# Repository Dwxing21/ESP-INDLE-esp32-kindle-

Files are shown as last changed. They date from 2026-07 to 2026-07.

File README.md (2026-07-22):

# ESPINDLE — DIY e-reader (ESP32-S3 + ILI9341 TFT)

A small, portable e-reader for manga, comics, and EPUB books. Built around
an **ESP32-S3 DevKit** and a **2.8" ILI9341 SPI TFT with an onboard
microSD slot**, in a 3D-printed case. Reads pages off the SD card, can
import `.epub` files directly on-device (no PC needed), and shows a
custom boot splash on power-up.

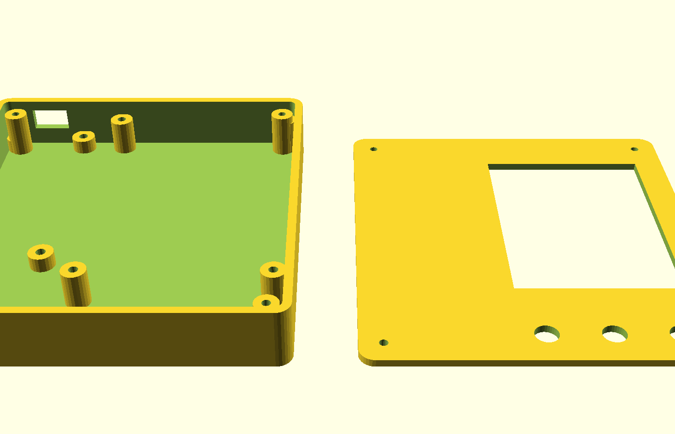
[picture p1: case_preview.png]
case preview


---

## Features
- **Manga / comic reader** — 240×320 JPEG pages off the SD card
- **EPUB import on-device** — drop `.epub` files onto the SD card, the
  device unpacks, re-flows, and paginates them into the library
- **Custom boot splash** — a 240×320 JPEG baked into flash, shown
  immediately on power-up before the SD card finishes initializing
- **Sleep / wake** — backlight dims to off after 5 minutes idle; any
  button press wakes it
- **3-button control** — Next, Previous, and a Select/Back button
  (short press = select, long press = back)

---

## Parts list
- **ESP32-S3 DevKit** — any generic ESP32-S3-DevKitC-1 (N16R8, N8R2, etc.
  all fine; ~€5-8)
- **2.8" ILI9341 SPI TFT with onboard microSD slot** — make sure the
  listing says **ILI9341** (not ST7789/ILI9488) and **SPI** (not
  parallel). Touch or non-touch doesn't matter. (~€4-7)
- **3× momentary tactile push buttons** — the small 4-leg square kind
  used on breadboards
- **microSD card** — 32 GB or less, formatted **FAT32**
- **Breadboard + jumper wires** — half-size or full-size breadboard,
  male-male and male-female jumpers
- Optional: **LiPo battery + TP4056** charge/protection board for
  portable use

**Total: ~€20-30** depending on supplier.

---

## 1. Wiring

Your 2.8" ILI9341 board shares one SPI bus between the screen and the
SD card — you only wire SCK/MOSI/MISO once, then give the screen and
the SD card their own chip-select (CS) lines.

| Screen/SD pin | ESP32-S3 GPIO | Notes |
|---|---|---|
| VCC | 3.3V | **Not 5V** — most of these boards are 3.3V only |
| GND | GND | |
| CS (TFT_CS) | GPIO 10 | Screen chip-select |
| RESET | GPIO 8 | |
| DC / RS | GPIO 9 | |
| SDI / MOSI | GPIO 11 | Shared with SD |
| SCK | GPIO 12 | Shared with SD |
| SDO / MISO | GPIO 13 | Shared with SD |
| LED (backlight) | GPIO 14 | PWM-driven for dimming/sleep |
| SD_CS | GPIO 15 | SD card chip-select |
| SD_MOSI/SCK/MISO | (same as above) | Same physical wires as the screen |

| Button | ESP32-S3 GPIO | Wiring |
|---|---|---|
| Next page | GPIO 4 | Button between pin and GND (internal pull-up used) |
| Previous page | GPIO 5 | Same |
| Select / Back | GPIO 6 | Short press = select, long press = back |

> **4-leg tactile buttons — check the orientation.** Most small tactile
> buttons have 4 legs arranged in 2 pairs: two legs on one side are
> permanently connected to each other, and the two legs on the other
> side are permanently connected to each other. Pressing the button
> bridges *those two pairs* together — it does **not** connect all 4
> legs. If you accidentally wire both your GPIO and GND wires to legs
> on the *same* side, the pin will read as permanently pressed (always
> LOW) whether you press it or not, and the button will appear
> completely dead. Use a multimeter's continuity mode to confirm: two
> legs should read "connected" with the button untouched, and only
> pressing it should connect the other two.

> These GPIOs are just a sensible default free of conflicts with
> USB/flash pins on most S3 boards. If your specific board already uses
> GPIO 8/9/10 for something else (check its pinout diagram), just change
> the `#define` values at the top of `espindle.ino` to match — nothing
> else needs to change.

Power the whole thing from the ESP32-S3's 5V/USB input; the board's
onboard regulator supplies 3.3V to itself, and you tap 3.3V from the
ESP32-S3 for the screen/SD.

---

## 2. Arduino IDE setup

1. Install **Arduino IDE 2.x**.
2. Add the ESP32 board package: *File → Preferences → Additional Board
   URLs* →
   `https://raw.githubusercontent.com/espressif/arduino-esp32/gh-pages/package_esp32_index.json`
3. *Tools → Board → Boards Manager* → search "esp32" → install the
   Espressif package.
4. Select your board: *Tools → Board → ESP32 Arduino → ESP32S3 Dev
   Module*.
5. Install libraries via *Sketch → Include Library → Manage Libraries*:
   - **Adafruit GFX Library**
   - **Adafruit ILI9341**
   - **TJpg_Decoder** (by Bodmer)
   - **unzipLIB** (by bitbank2) — needed for the on-device EPUB
     import feature
   - `SD` is bundled with the ESP32 core — no install needed.
6. **Important:** open the sketch by opening the `espindle.ino` file
   directly. `splash_jpeg.h` must live in the **same folder** as
   `espindle.ino` — the firmware `#include`s it with a relative path,
   so if you move or rename the header the build will fail.
7. Select the correct COM port and upload.

---

## 3. The boot splash

The splash image is **baked into flash** as a PROGMEM byte array in
`splash_jpeg.h` — there's no splash file to copy to the SD card. It
shows up immediately on power-up and stays on screen through the SD
card initialization (the slowest step of boot), so the user always gets
visual feedback within a second of plugging in.

To change the splash to your own image:
1. Get a JPEG you like, ideally already 240×320 (or close to that
   aspect ratio).
2. Run `img.py` against it to resize and re-encode:
   ```bash
   python3 img.py
   ```
   (Edit the `img.py` source/filenames if needed — by default it reads
   `espindel boot screen.jpg` and writes `splash.jpg`.)
3. Replace the `splash_jpeg` byte array in `splash_jpeg.h` with the
   bytes of the new file. Easiest way:
   ```bash
   xxd -i splash.jpg | sed 's/splash_jpg/splash_jpeg/g' > splash_jpeg.h
   ```
   then update the `#define SPLASH_JPEG_LEN` line at the top to the
   new file's byte count.

If the splash JPEG is corrupted or missing, the firmware will simply
fall back to a black screen during boot — the rest of the app still
works.

---

## 4. Preparing the SD card

1. Format the microSD card as **FAT32**.
2. Create this folder structure on it:
   ```
   /manga/One Piece/Chapter 1001/001.jpg
   /manga/One Piece/Chapter 1001/002.jpg
   /manga/Berserk/Chapter 001/001.jpg
   ```
3. Filenames inside a chapter must be **zero-padded and sequential**
   (`001.jpg`, `002.jpg`, …) so they sort correctly — the firmware
   sorts pages alphabetically.
4. Insert the card into the reader's SD slot before powering on.

The section below shows how to generate exactly this structure
automatically.

---

## 5. Getting manga/comics onto the SD card as JPEGs

A quick note first: only load content you're legally entitled to read
this way — things like your own scanned physical volumes, comics you've
bought as digital files (CBZ/CBR/PDF), or officially released
free/public-domain comics. Pirating scans isn't something I'll help
source.

### Where your source files usually come from
- **Digital purchases** (ComiXology/Kindle, Book Walker, publisher
  storefronts) — usually download as CBZ, CBR, EPUB, or PDF.
- **Your own scans** of physical volumes — typically end up as a
  folder of JPG/PNG or a PDF from your scanning software.
- **Public domain / Creative-Commons comics** — usually distributed
  directly as image sets or PDFs.

### Step A — Get everything into loose image files
- **CBZ** files are literally ZIP archives — rename `.cbz` to `.zip`
  (or just open with any archive tool) and extract.
- **CBR** files are RAR archives — extract with 7-Zip, WinRAR, or
  `unar`, then treat like CBZ.
- **PDF** source — extract each page as an image:
  - **Free tool (all platforms):** [XnConvert](https://www.xnview.com/en/xnconvert/)
    or `pdftoppm` (part of Poppler) — e.g. `pdftoppm -jpeg book.pdf page`
  - **Mac:** Preview → File → Export as JPEG, or use `sips`/`pdftoppm`
    via Homebrew.
  - **Windows:** Poppler for Windows (`pdftoppm.exe`) or any free
    "PDF to JPG" desktop tool.

### Step B — Resize, rename, and organize automatically
Doing this by hand for hundreds of pages is painful, so use the
included **`prepare_manga.py`** script. It takes a folder of images
(or CBZ files) and outputs a properly-sized, correctly-named
`/manga/...` folder tree ready to drop onto the SD card.

```bash
pip install pillow

# From a folder of loose images:
python prepare_manga.py --input "path/to/OnePiece_Ch1001" --series "One Piece" --chapter "Chapter 1001" --output "SD_CARD_ROOT/manga"

# Directly from a CBZ file:
python prepare_manga.py --input "path/to/Berserk_001.cbz" --series "Berserk" --chapter "Chapter 001" --output "SD_CARD_ROOT/manga"
```

Point `--output` at the `manga` folder on your actual SD card (once
it's mounted on your computer) and the script writes the finished
folder structure directly onto it. Run it once per chapter, or see the
`--batch` option in the script for converting a whole folder of
chapter subfolders at once.

The script:
- Resizes/crops each page to fit the 240×320 screen (preserving
  aspect ratio, so no stretching)
- Converts everything to JPEG at a size-friendly quality (85) so
  pages load fast off the SD card
- Renames pages sequentially as `001.jpg`, `002.jpg`, … so they
  always sort correctly
- Unpacks CBZ files automatically if you point `--input` at a `.cbz`
  instead of a folder

### Step C — Load the card
Copy (or let the script write directly to) the finished
`manga/<Series>/<Chapter>/*.jpg` folders onto the SD card, eject
safely, and insert into the reader.

---

## 6. EPUB import (on-device)

See **[EPUB_IMPORT.md](EPUB_IMPORT.md)** for the full guide. Short
version: drop `.epub` files into `/epub_import/` on the SD card, pick
**+ Import EPUB...** from the main menu on the device, and the
ESP32-S3 itself unpacks, re-flows, and paginates them into the
library.

---

## 7. Using the reader
- **Next / Previous** buttons move through the series list, chapter
  list, or pages depending on where you are.
- **Select** (short press) confirms a menu choice, or shows a
  page-number overlay while reading.
- **Select** (long press, ~0.6s) goes back a menu level.
- After 5 minutes idle, the backlight turns off to save power; any
  button press wakes it (the first press just wakes the screen and is
  otherwise ignored).

---

## Files in this repo
- `espindle.ino` — the main firmware
- `splash_jpeg.h` — the boot splash image, baked into flash
- `prepare_manga.py` — PC-side script for resizing/renaming comic
  pages onto the SD card
- `case.scad` / `case_base.stl` / `case_lid.stl` / `case_preview.png`
  — the 3D-printed case
- `EPUB_IMPORT.md` — detailed EPUB import guide
- `img.py` — utility for regenerating `splash_jpeg.h` from a new
  source image

---

## License / content notice
This project is just hardware and code. **What you read on it is your
responsibility** — only load books and comics you're legally entitled
to read this way (your own purchases, public domain works, your own
scans of physical media you own, etc.).

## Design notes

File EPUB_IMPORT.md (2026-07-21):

# EPUB Import — On-Device, No PC Needed

## What it does
Adds a **"+ Import EPUB..."** entry at the top of the main menu. Selecting
it lets you pick any `.epub` file sitting in a folder on the SD card, and
the ESP32-S3 itself unzips it, extracts the chapter text, re-flows it to
fit the screen, and saves it into your library — all on the device, no
computer involved.

## How to use it
1. Copy `.epub` files onto the SD card into a folder named `/epub_import`
   (the firmware creates this folder automatically on first boot if it
   doesn't exist yet — you just need to drop files into it).
2. On the device, open the main menu and select **+ Import EPUB...**
3. Pick a file from the list and press Select.
4. Wait while it converts — you'll see a progress screen counting through
   chapters (this can take anywhere from several seconds to a couple of
   minutes depending on the book's length; text-only books are much
   faster than image-heavy ones since there's no JPEG decoding involved).
5. When it's done, you're dropped back at the main menu with the new book
   already in your library, ready to read with the exact same
   Next/Prev/Select controls as manga chapters.

## What it can and can't do
- **Can:** extract and paginate the actual reading text of standard
  "reflowable" EPUB books — novels, most non-fiction, etc.
- **Can't:** render embedded images, custom fonts, complex CSS layouts,
  or "fixed layout" EPUBs (the kind used for comics/picture books — use
  the manga pipeline for those instead, via `prepare_manga.py`).
- The EPUB/HTML parsing uses lightweight pattern-matching rather than a
  full XML parser, to keep it practical on a microcontroller. It handles
  the great majority of real-world EPUB files correctly, but an unusual
  or malformed one could occasionally produce a slightly rough result
  (e.g. a stray heading picked up as a chapter title, or a missing
  chapter if its manifest entry is unusual). If a specific book converts
  oddly, let me know the details and I can tune the parser.

## Where things end up on the SD card
```
/epub_import/mybook.epub          <- source file you dropped in
/manga/My Book Title/
  001 - Chapter One/
    001.txt
    002.txt
    ...
  002 - Chapter Two/
    001.txt
    ...
```
This is the same folder structure as manga chapters, just with `.txt`
page files instead of `.jpg` — the reader already treats both the same
way once you're browsing the menu.

## Only import books you're legally entitled to read this way
Your own purchases, your own writing, and public domain works are all
fine. This feature converts files already on your SD card — it doesn't
fetch or download anything from anywhere.

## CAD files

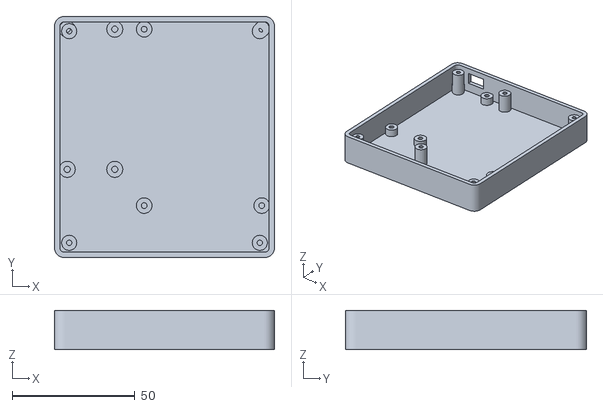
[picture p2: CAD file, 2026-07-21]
case_base.stl
89.8 x 98.4 x 16.0

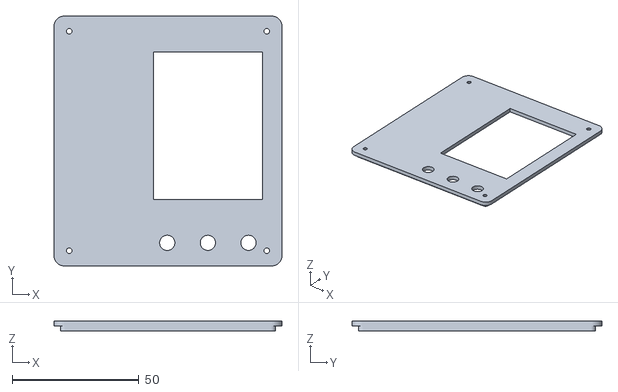
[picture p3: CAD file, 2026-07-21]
case_lid.stl
89.8 x 98.4 x 4.00

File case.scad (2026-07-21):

// ============================================================
// ESPINDLE Case — parametric OpenSCAD source
// ============================================================
// MEASURE YOUR OWN BOARDS WITH CALIPERS AND ADJUST THE VALUES
// BELOW BEFORE PRINTING. The defaults are typical sizes for a
// generic 2.8" ILI9341 SPI+SD breakout and an ESP32-S3-DevKitC-1
// style board, but real dimensions vary between suppliers.
// ============================================================

// ---------- Which part to render ----------
// "base" = bottom shell (holds the boards)
// "lid"  = top shell (screen window + buttons)
// "both" = both, side by side (preview only, don't print this way)
PART = "both"; // [base, lid, both]

// ---------- General ----------
wall        = 2.2;   // outer wall thickness
floor_t     = 2.0;   // base floor thickness
lid_t       = 2.0;   // lid thickness
gap         = 0.3;   // clearance between base walls and lid
corner_r    = 4;     // outer corner rounding radius

// ---------- TFT board (2.8" ILI9341 + SD) ----------
tft_w       = 54;    // board width (short axis)
tft_h       = 78;    // board length (long axis, includes header strip)
tft_thick   = 3.2;   // board PCB + connector thickness, for standoff height
tft_active_w = 43;   // visible screen width
tft_active_h = 58;   // visible screen height
tft_active_off_x = (tft_w - tft_active_w) / 2; // horizontal centering — adjust if off-center on your board
tft_active_off_y = 8;                          // gap from top edge of board to top of visible screen — MEASURE THIS
tft_mount_inset  = 3; // distance from board edge to its mounting-hole centers (adjust to your board's holes)
tft_hole_dia     = 2.4; // screw/standoff hole diameter for TFT board

// ---------- ESP32-S3 DevKitC-1 style board ----------
esp_w       = 25.4;
esp_h       = 63.2;
esp_thick   = 8;     // clearance height needed under/around the board (USB connector, headers)
esp_mount_inset = 3;
esp_hole_dia    = 2.6;

// ---------- Buttons (3x, front edge of lid, thumb reach) ----------
btn_hole_dia = 6.0;
btn_spacing  = 16;

// ---------- Print bed ----------
// da Vinci mini's actual spec'd build volume is 150x150x150mm — designing
// to this (with a small margin) fits both that and a 160x160 bed.
max_plate_xy = 148;

// ---------- Layout (side-by-side, not stacked — keeps the case short) ----------
column_gap    = 6;    // horizontal gap between the TFT and ESP32 columns, for wiring
button_zone_h = 16;   // strip reserved below the TFT board for buttons
lip_frame_w   = 2.5;  // width of the lid's thin alignment rim — must NOT cover the interior

inner_w = tft_w + column_gap + esp_w;
inner_h = tft_h + button_zone_h;                      // tallest column (TFT) + its button strip
inner_d = max(tft_thick, esp_thick) + 6;               // boards are side-by-side, so depth = the taller one, not the sum

outer_w = inner_w + 2 * wall;
outer_h = inner_h + 2 * wall;
outer_d = inner_d + floor_t + lid_t;

// Standoff post height for TFT board (raises its top surface near the lid window)
tft_standoff_h = inner_d - tft_thick - 1;
// Standoff post height for ESP32 board (mounted lower, doesn't need to reach the lid)
esp_standoff_h = 4;

echo(str("Overall case size (mm): ", outer_w, " x ", outer_h, " x ", outer_d));
if (outer_w > max_plate_xy || outer_h > max_plate_xy) {
  echo(str("*** WARNING: case footprint exceeds ", max_plate_xy, "mm — will NOT fit the print bed! ***"));
}

// ============================================================
// Helper modules
// ============================================================
module rounded_rect(w, h, r) {
  hull() {
    for (x = [r, w - r])
      for (y = [r, h - r])
        translate([x, y, 0]) circle(r = r, $fn = 32);
  }
}

module standoff(hole_dia, height) {
  difference() {
    cylinder(d = hole_dia + 4, h = height, $fn = 24);
    translate([0, 0, -0.5]) cylinder(d = hole_dia, h = height + 1, $fn = 16);
  }
}

// corner screw bosses joining base + lid (self-tapping screws, e.g. M2.5)
module corner_bosses(w, h, height, hole_dia = 2.2, inset = 6) {
  positions = [[inset, inset], [w - inset, inset], [inset, h - inset], [w - inset, h - inset]];
  for (p = positions)
    translate([p[0], p[1], 0])
      standoff(hole_dia, height);
}

// ============================================================
// BASE (bottom shell)
// ============================================================
module case_base() {
  // Both boards top-aligned to the same interior top edge; TFT column has a
  // button strip below it, ESP32 column has empty space below (for wiring/battery).
  esp_x = wall;
  tft_x = wall + esp_w + column_gap;
  tft_y = wall + button_zone_h; // top-aligned with esp_y + esp_h below
  esp_y = wall + inner_h - esp_h; // top-aligned to same interior top as TFT

  difference() {
    union() {
      // outer shell
      linear_extrude(height = floor_t + inner_d)
        rounded_rect(outer_w, outer_h, corner_r);
    }
    // hollow out interior, leave floor
    translate([wall, wall, floor_t])
      linear_extrude(height = inner_d + 1)
        rounded_rect(inner_w, inner_h, corner_r - wall > 0 ? corner_r - wall : 1);

    // USB-C access cutout — top wall, aligned to the ESP32 board's top edge
    // (adjust which wall this is on if your board's USB connector is elsewhere)
    translate([esp_x + esp_w/2 - 5, outer_h - wall - 1, floor_t + esp_standoff_h + 1])
      cube([10, wall + 2, 6]);
  }

  // TFT board standoffs
  translate([tft_x + tft_mount_inset, tft_y + tft_mount_inset, floor_t])
    standoff(tft_hole_dia, tft_standoff_h);
  translate([tft_x + tft_w - tft_mount_inset, tft_y + tft_mount_inset, floor_t])
    standoff(tft_hole_dia, tft_standoff_h);
  translate([tft_x + tft_mount_inset, tft_y + tft_h - tft_mount_inset, floor_t])
    standoff(tft_hole_dia, tft_standoff_h);
  translate([tft_x + tft_w - tft_mount_inset, tft_y + tft_h - tft_mount_inset, floor_t])
    standoff(tft_hole_dia, tft_standoff_h);

  // ESP32-S3 board standoffs
  translate([esp_x + esp_mount_inset, esp_y + esp_mount_inset, floor_t])
    standoff(esp_hole_dia, esp_standoff_h);
  translate([esp_x + esp_w - esp_mount_inset, esp_y + esp_mount_inset, floor_t])
    standoff(esp_hole_dia, esp_standoff_h);
  translate([esp_x + esp_mount_inset, esp_y + esp_h - esp_mount_inset, floor_t])
    standoff(esp_hole_dia, esp_standoff_h);
  translate([esp_x + esp_w - esp_mount_inset, esp_y + esp_h - esp_mount_inset, floor_t])
    standoff(esp_hole_dia, esp_standoff_h);

  // corner screw bosses (joins to lid)
  corner_bosses(outer_w, outer_h, floor_t + inner_d - 2);
}

// ============================================================
// LID (top shell)
// ============================================================
module case_lid() {
  esp_x = wall;
  tft_x = wall + esp_w + column_gap;
  tft_y = wall + button_zone_h;
  esp_y = wall + inner_h - esp_h;

  difference() {
    union() {
      linear_extrude(height = lid_t)
        rounded_rect(outer_w, outer_h, corner_r);
      // thin alignment rim (frame, not a plate) that nests inside the base walls —
      // only the outer lip_frame_w band is solid, the interior stays open so it
      // can never block the screen window, button holes, or wire routing space.
      translate([wall + gap, wall + gap, -2])
        linear_extrude(height = 2)
          difference() {
            rounded_rect(inner_w - 2*gap, inner_h - 2*gap, max(corner_r - wall, 1));
            translate([lip_frame_w, lip_frame_w, 0])
              rounded_rect(inner_w - 2*gap - 2*lip_frame_w, inner_h - 2*gap - 2*lip_frame_w,
                            max(corner_r - wall - lip_frame_w, 0.5));
          }
    }

    // screen window, aligned over the TFT board's active area
    // (cut depth -3 to lid_t+2 so it fully clears the rim's z=-2 to 0 span too)
    translate([tft_x + tft_active_off_x, tft_y + tft_active_off_y, -3])
      linear_extrude(height = lid_t + 5)
        square([tft_active_w, tft_active_h]);

    // button holes — centered under the TFT column's screen, in its button strip
    btn_y = button_zone_h / 2 + wall/2;
    btn_center_x = tft_x + tft_w/2;
    for (i = [-1, 0, 1])
      translate([btn_center_x + i * btn_spacing, btn_y, -3])
        cylinder(d = btn_hole_dia, h = lid_t + 5, $fn = 32);

    // corner screw holes (through-holes matching base bosses)
    positions = [[6, 6], [outer_w - 6, 6], [6, outer_h - 6], [outer_w - 6, outer_h - 6]];
    for (p = positions)
      translate([p[0], p[1], -3])
        cylinder(d = 2.2, h = lid_t + 5, $fn = 16);
  }
}
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

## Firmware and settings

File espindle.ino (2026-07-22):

/*
  ============================================================
  ESPINDLE — ESP32-S3 Manga/Comic/EPUB Reader
  (ESP + Kindle)
  ============================================================
  Hardware: ESP32-S3 DevKit + 2.8" ILI9341 SPI TFT w/ SD slot

  SD card layout expected:
    /manga/<Title>/<Chapter Name>/001.jpg   (image pages -- comics/manga)
    /manga/<Title>/<Chapter Name>/001.txt   (text pages -- imported EPUBs)
    ...
  (Use prepare_manga.py on a PC to generate the image version, or use
  the on-device "+ Import EPUB..." menu option to generate the text
  version directly from a .epub file dropped in /epub_import -- no PC
  needed for that path.)

  EPUB IMPORT NOTES:
  - Only import EPUB files you're legally entitled to read this way
    (your own books, purchases, public domain works) -- same principle
    as the manga content.
  - The importer only handles reflowable text content: chapter text is
    extracted and re-flowed to fit the screen. Embedded images, custom
    fonts, and complex CSS layouts in the EPUB are not rendered.
  - OPF/HTML parsing here uses lightweight heuristics (string search),
    not a full XML parser, to keep this practical on a microcontroller.
    It works on the great majority of real-world EPUB files but isn't
    guaranteed to handle every possible malformed or unusual one.

  Libraries required (install via Library Manager):
    - Adafruit GFX Library
    - Adafruit ILI9341
    - TJpg_Decoder (by Bodmer)
    - unzipLIB (by bitbank2)      <-- new, needed for EPUB import
    - SD (bundled with ESP32 core)

  Wiring: see WIRING_GUIDE.md
  ============================================================
*/

#include <SPI.h>
#include <SD.h>
#include <Adafruit_GFX.h>
#include <Adafruit_ILI9341.h>
#include <TJpg_Decoder.h>
#include <unzipLIB.h>
#include <vector>
#include <algorithm>
#include "splash_jpeg.h"

// ---------------- PIN CONFIG ----------------
// Shared SPI bus (TFT + SD)
#define PIN_SCK   12
#define PIN_MOSI  11
#define PIN_MISO  13

#define TFT_CS    10
#define TFT_DC    9
#define TFT_RST   8
#define TFT_LED   14   // backlight, PWM controlled

#define SD_CS     15

// Buttons (active LOW, wired to GND with internal pullups)
#define BTN_NEXT   4
#define BTN_PREV   5
#define BTN_SELECT 6

// ---------------- SCREEN ----------------
#define SCREEN_W 240
#define SCREEN_H 320

SPIClass spiBus = SPIClass(HSPI);
// Bound explicitly to spiBus (not the default global SPI object) so this
// works correctly regardless of what a given ESP32-S3 board's default
// hardware SPI pins happen to be.
Adafruit_ILI9341 tft = Adafruit_ILI9341(&spiBus, TFT_DC, TFT_CS, TFT_RST);

// ---------------- BACKLIGHT / SLEEP ----------------
#define IDLE_TIMEOUT_MS   (5UL * 60UL * 1000UL)  // 5 minutes
unsigned long lastActivity = 0;
bool screenDimmed = false;

// ---------------- LIBRARY / FOLDER LAYOUT ----------------
#define MANGA_ROOT       "/manga"
#define EPUB_IMPORT_DIR  "/epub_import"
static const char *IMPORT_EPUB_LABEL = "+ Import EPUB...";

// ---------------- TEXT PAGE LAYOUT (for imported EPUB chapters) ----------------
#define TEXT_SIZE        1   // Adafruit default font: 6px/char wide, 8px/line tall at size 1
#define TEXT_MARGIN      6
#define TEXT_CHAR_W      (6 * TEXT_SIZE)
#define TEXT_LINE_H      (8 * TEXT_SIZE)
#define TEXT_CHARS_PER_LINE  ((SCREEN_W - 2*TEXT_MARGIN) / TEXT_CHAR_W)
#define TEXT_LINES_PER_PAGE  ((SCREEN_H - 2*TEXT_MARGIN) / TEXT_LINE_H - 1) // -1 line of headroom

// ---------------- APP STATE ----------------
enum AppState { STATE_SERIES_MENU, STATE_CHAPTER_MENU, STATE_READING, STATE_EPUB_PICKER };
AppState appState = STATE_SERIES_MENU;

std::vector<String> seriesList;
std::vector<String> chapterList;
std::vector<String> pageList;
std::vector<String> epubFileList;

int seriesIndex = 0;
int chapterIndex = 0;
int pageIndex = 0;
int epubIndex = 0;
int menuScrollTop = 0;
const int MENU_VISIBLE_ROWS = 12;

String currentSeriesPath = "";
String currentChapterPath = "";

// ---------------- BUTTON DEBOUNCE ----------------
struct Button {
  uint8_t pin;
  bool rawState = HIGH;      // last raw (possibly bouncy) pin reading
  bool stableState = HIGH;   // debounce-confirmed state
  unsigned long lastChange = 0;
  unsigned long pressStart = 0;
  bool longPressFired = false;
};
Button btnNext   = {BTN_NEXT};
Button btnPrev   = {BTN_PREV};
Button btnSelect = {BTN_SELECT};

const unsigned long DEBOUNCE_MS   = 30;
const unsigned long LONGPRESS_MS  = 600;

// ---------------- EPUB IMPORT (unzipLIB) ----------------
UNZIP epubZip; // statically allocated per library docs (~41KB)
static File epubZipFile; // backing file for the SD callbacks below

// Callback functions unzipLIB needs to read a zip file from the SD card
// (pattern taken directly from the library's own SD card example --
// note the library passes a ZIPFILE* wrapper to close/read/seek, not the
// raw pointer returned by open(); the real File* lives in ->fHandle).
void *epubZipOpen(const char *filename, int32_t *size) {
  epubZipFile = SD.open(filename);
  if (!epubZipFile) { *size = 0; return NULL; }
  *size = epubZipFile.size();
  return (void *)&epubZipFile;
}
void epubZipClose(void *p) {
  ZIPFILE *pzf = (ZIPFILE *)p;
  File *f = (File *)pzf->fHandle;
  if (f) f->close();
}
int32_t epubZipRead(void *p, uint8_t *buffer, int32_t length) {
  ZIPFILE *pzf = (ZIPFILE *)p;
  File *f = (File *)pzf->fHandle;
  return f->read(buffer, length);
}
int32_t epubZipSeek(void *p, int32_t position, int iType) {
  ZIPFILE *pzf = (ZIPFILE *)p;
  File *f = (File *)pzf->fHandle;
  if (iType == SEEK_SET) return f->seek(position) ? position : -1;
  else if (iType == SEEK_END) return f->seek(pzf->iSize + position) ? (pzf->iSize + position) : -1;
  else { long l = f->position(); return f->seek(l + position) ? (l + position) : -1; }
}

// ============================================================
// JPEG DECODER CALLBACK — draws each decoded MCU block to TFT
// ============================================================
bool tft_output(int16_t x, int16_t y, uint16_t w, uint16_t h, uint16_t *bitmap) {
  if (y >= tft.height()) return 0;
  tft.drawRGBBitmap(x, y, bitmap, w, h);
  return 1;
}

// ============================================================
// SETUP
// ============================================================
void setup() {
  Serial.begin(115200);

  pinMode(BTN_NEXT, INPUT_PULLUP);
  pinMode(BTN_PREV, INPUT_PULLUP);
  pinMode(BTN_SELECT, INPUT_PULLUP);

  // Backlight PWM (ESP32 Arduino core 3.x pin-based LEDC API)
  ledcAttach(TFT_LED, 5000, 8); // pin, freq Hz, resolution bits
  ledcWrite(TFT_LED, 255);      // full brightness

  // Shared SPI bus for TFT + SD
  spiBus.begin(PIN_SCK, PIN_MISO, PIN_MOSI, TFT_CS);
  tft.begin();
  tft.setRotation(0); // portrait, best for manga pages
  tft.fillScreen(ILI9341_BLACK);

  // Boot splash: show the flash-baked splash.jpeg immediately so the user
  // sees feedback while SD init runs (the slowest part of boot).
  drawSplashFromFlash();

  if (!SD.begin(SD_CS, spiBus)) {
    drawFatalError("SD card not found!\nCheck wiring/card.");
    while (true) delay(1000);
  }

  if (!SD.exists(EPUB_IMPORT_DIR)) SD.mkdir(EPUB_IMPORT_DIR);

  TJpgDec.setJpgScale(1);
  TJpgDec.setSwapBytes(true);
  TJpgDec.setCallback(tft_output);

  loadSeriesList();
  drawMenu();

  lastActivity = millis();
}

// ============================================================
// MAIN LOOP
// ============================================================
void loop() {
  bool nextPressed   = readButton(btnNext);
  bool prevPressed   = readButton(btnPrev);
  bool selectPressed = readButtonWithLongPress(btnSelect);

  if (nextPressed || prevPressed || selectPressed) {
    lastActivity = millis();
    if (screenDimmed) {
      wakeScreen();
      return; // swallow the wake press
    }
  }

  handleIdleSleep();

  if (screenDimmed) { delay(20); return; }

  if (nextPressed)   handleNext();
  if (prevPressed)   handlePrev();
  if (selectPressed) handleSelect();

  delay(10);
}

// ============================================================
// BUTTON HELPERS
// ============================================================
bool readButton(Button &b) {
  bool reading = digitalRead(b.pin);
  bool pressed = false;

  if (reading != b.rawState) b.lastChange = millis();
  b.rawState = reading;

  if ((millis() - b.lastChange) > DEBOUNCE_MS) {
    if (reading != b.stableState) {
      b.stableState = reading;
      if (b.stableState == LOW) pressed = true; // confirmed press edge
    }
  }
  return pressed;
}

// SELECT button: short press = confirm, long press = back
// Returns true only on SHORT press release (confirm action)
bool readButtonWithLongPress(Button &b) {
  bool reading = digitalRead(b.pin);
  bool shortPress = false;

  if (reading != b.rawState) b.lastChange = millis();
  b.rawState = reading;

  if ((millis() - b.lastChange) > DEBOUNCE_MS) {
    if (reading != b.stableState) {
      // confirmed transition
      b.stableState = reading;
      if (b.stableState == LOW) {
        b.pressStart = millis();
        b.longPressFired = false;
      } else if (!b.longPressFired) {
        shortPress = true; // confirmed release, wasn't a long press
      }
    }

    // check for long-press while still held down
    if (b.stableState == LOW && !b.longPressFired) {
      if (millis() - b.pressStart > LONGPRESS_MS) {
        b.longPressFired = true;
        goBack();
      }
    }
  }
  return shortPress;
}

// ============================================================
// NAVIGATION LOGIC
// ============================================================
void handleNext() {
  if (appState == STATE_READING) {
    if (pageIndex < (int)pageList.size() - 1) {
      pageIndex++;
      showPage();
    }
  } else if (appState == STATE_EPUB_PICKER) {
    if (epubIndex < (int)epubFileList.size() - 1) { epubIndex++; drawEpubPickerMenu(); }
  } else {
    int count = (appState == STATE_SERIES_MENU) ? seriesList.size() : chapterList.size();
    int &idx = (appState == STATE_SERIES_MENU) ? seriesIndex : chapterIndex;
    if (idx < count - 1) { idx++; drawMenu(); }
  }
}

void handlePrev() {
  if (appState == STATE_READING) {
    if (pageIndex > 0) {
      pageIndex--;
      showPage();
    }
  } else if (appState == STATE_EPUB_PICKER) {
    if (epubIndex > 0) { epubIndex--; drawEpubPickerMenu(); }
  } else {
    int &idx = (appState == STATE_SERIES_MENU) ? seriesIndex : chapterIndex;
    if (idx > 0) { idx--; drawMenu(); }
  }
}

void handleSelect() {
  if (appState == STATE_SERIES_MENU) {
    if (seriesList.empty()) return;
    if (seriesList[seriesIndex] == IMPORT_EPUB_LABEL) {
      enterEpubPicker();
      return;
    }
    currentSeriesPath = String(MANGA_ROOT) + "/" + seriesList[seriesIndex];
    loadChapterList(currentSeriesPath);
    chapterIndex = 0;
    appState = STATE_CHAPTER_MENU;
    drawMenu();
  } else if (appState == STATE_CHAPTER_MENU) {
    if (chapterList.empty()) return;
    currentChapterPath = currentSeriesPath + "/" + chapterList[chapterIndex];
    loadPageList(currentChapterPath);
    if (pageList.empty()) return; // chapter had no valid page files -- stay on chapter menu
    pageIndex = 0;
    appState = STATE_READING;
    showPage();
  } else if (appState == STATE_READING) {
    // toggle a quick page counter overlay
    drawPageOverlay();
  } else if (appState == STATE_EPUB_PICKER) {
    if (epubFileList.empty()) return;
    String path = String(EPUB_IMPORT_DIR) + "/" + epubFileList[epubIndex];
    runEpubImport(path);
  }
}

void goBack() {
  if (appState == STATE_READING) {
    appState = STATE_CHAPTER_MENU;
    drawMenu();
  } else if (appState == STATE_CHAPTER_MENU) {
    appState = STATE_SERIES_MENU;
    drawMenu();
  } else if (appState == STATE_EPUB_PICKER) {
    appState = STATE_SERIES_MENU;
    drawMenu();
  }
  // already at series menu: long-press does nothing further
}

// ============================================================
// SD DIRECTORY LOADING
// ============================================================
void loadSeriesList() {
  seriesList.clear();
  File dir = SD.open(MANGA_ROOT);
  if (!dir) { drawFatalError("No /manga folder\non SD card."); while (true) delay(1000); }
  while (File entry = dir.openNextFile()) {
    if (entry.isDirectory()) seriesList.push_back(String(entry.name()));
    entry.close();
  }
  dir.close();
  sortStrings(seriesList);
  seriesList.insert(seriesList.begin(), String(IMPORT_EPUB_LABEL));
}

void loadChapterList(const String &seriesPath) {
  chapterList.clear();
  File dir = SD.open(seriesPath);
  if (!dir) return;
  while (File entry = dir.openNextFile()) {
    if (entry.isDirectory()) chapterList.push_back(String(entry.name()));
    entry.close();
  }
  dir.close();
  sortStrings(chapterList);
}

void loadPageList(const String &chapterPath) {
  pageList.clear();
  File dir = SD.open(chapterPath);
  if (!dir) return;
  while (File entry = dir.openNextFile()) {
    if (!entry.isDirectory()) {
      String name = String(entry.name());
      String lower = name; lower.toLowerCase();
      if (lower.endsWith(".jpg") || lower.endsWith(".jpeg") || lower.endsWith(".txt")) {
        pageList.push_back(name);
      }
    }
    entry.close();
  }
  dir.close();
  sortStrings(pageList); // relies on zero-padded filenames, e.g. 001.jpg / 001.txt
}

void sortStrings(std::vector<String> &v) {
  std::sort(v.begin(), v.end(), [](const String &a, const String &b) {
    return a < b;
  });
}

// ============================================================
// DRAWING
// ============================================================
void drawStatus(const char *msg) {
  tft.fillScreen(ILI9341_BLACK);
  tft.setTextColor(ILI9341_WHITE);
  tft.setTextSize(2);
  tft.setCursor(10, 140);
  tft.println(msg);
}

// Draws the boot splash image baked into flash (splash_jpeg[] from
// splash_jpeg.h). Renders centered on the 240x320 screen. If decoding
// fails for any reason, falls back to a blank black screen so the rest
// of setup() can still proceed.
void drawSplashFromFlash() {
  tft.fillScreen(ILI9341_BLACK);
  // drawJpg() with a (const uint8_t *, size_t) overload decodes from a
  // RAM/flash buffer via the existing tft_output callback.
  uint16_t result = TJpgDec.drawJpg(splash_jpeg, SPLASH_JPEG_LEN);
  if (result != TJpgDec.JPEG_OK) {
    tft.fillScreen(ILI9341_BLACK);
  }
}

void drawFatalError(const char *msg) {
  tft.fillScreen(ILI9341_RED);
  tft.setTextColor(ILI9341_WHITE);
  tft.setTextSize(2);
  tft.setCursor(10, 120);
  tft.println(msg);
}

void drawMenu() {
  tft.fillScreen(ILI9341_BLACK);
  tft.setTextSize(2);

  std::vector<String> *list;
  String title;
  int selected;

  if (appState == STATE_SERIES_MENU) {
    list = &seriesList; title = "Library"; selected = seriesIndex;
  } else {
    list = &chapterList; title = seriesList[seriesIndex]; selected = chapterIndex;
  }

  tft.setTextColor(ILI9341_YELLOW);
  tft.setCursor(6, 4);
  tft.println(title);
  tft.drawFastHLine(0, 26, SCREEN_W, ILI9341_YELLOW);

  if (list->empty()) {
    tft.setTextColor(ILI9341_WHITE);
    tft.setCursor(6, 40);
    tft.println("(empty)");
    return;
  }

  // keep selection in view
  if (selected < menuScrollTop) menuScrollTop = selected;
  if (selected >= menuScrollTop + MENU_VISIBLE_ROWS) menuScrollTop = selected - MENU_VISIBLE_ROWS + 1;

  int y = 32;
  for (int i = menuScrollTop; i < (int)list->size() && i < menuScrollTop + MENU_VISIBLE_ROWS; i++) {
    bool isSel = (i == selected);
    tft.fillRect(0, y, SCREEN_W, 20, isSel ? ILI9341_BLUE : ILI9341_BLACK);
    tft.setTextColor(isSel ? ILI9341_WHITE : ILI9341_LIGHTGREY);
    tft.setCursor(6, y + 2);
    tft.println((*list)[i]);
    y += 20;
  }
}

void showPage() {
  tft.fillScreen(ILI9341_BLACK);
  String name = pageList[pageIndex];
  String lower = name; lower.toLowerCase();
  String path = currentChapterPath + "/" + name;
  if (lower.endsWith(".txt")) {
    renderTextPage(path);
  } else {
    TJpgDec.drawSdJpg(0, 0, path.c_str());
  }
}

void drawPageOverlay() {
  char buf[24];
  snprintf(buf, sizeof(buf), "%d / %d", pageIndex + 1, (int)pageList.size());
  tft.fillRect(0, SCREEN_H - 24, SCREEN_W, 24, ILI9341_BLACK);
  tft.setTextColor(ILI9341_WHITE);
  tft.setTextSize(2);
  tft.setCursor(6, SCREEN_H - 20);
  tft.println(buf);
}

// Renders a pre-wrapped text page file -- each line in the file is already
// sized to fit the screen width (done at import time), so this just prints
// each line in order.
void renderTextPage(const String &path) {
  File f = SD.open(path);
  if (!f) {
    tft.setTextColor(ILI9341_RED);
    tft.setTextSize(2);
    tft.setCursor(10, 140);
    tft.println("Error reading page");
    return;
  }
  tft.setTextColor(ILI9341_WHITE);
  tft.setTextSize(TEXT_SIZE);
  int y = TEXT_MARGIN;
  while (f.available() && y < SCREEN_H - TEXT_MARGIN) {
    String line = f.readStringUntil('\n');
    tft.setCursor(TEXT_MARGIN, y);
    tft.println(line);
    y += TEXT_LINE_H;
  }
  f.close();
}

// ============================================================
// SLEEP / BACKLIGHT
// ============================================================
void handleIdleSleep() {
  if (!screenDimmed && (millis() - lastActivity > IDLE_TIMEOUT_MS)) {
    ledcWrite(TFT_LED, 0);
    screenDimmed = true;
  }
}

void wakeScreen() {
  ledcWrite(TFT_LED, 255);
  screenDimmed = false;
  lastActivity = millis();
}

// ============================================================
// EPUB IMPORT — everything below this line is the new feature
// ============================================================

void enterEpubPicker() {
  scanEpubFolder();
  epubIndex = 0;
  appState = STATE_EPUB_PICKER;
  drawEpubPickerMenu();
}

void scanEpubFolder() {
  epubFileList.clear();
  File dir = SD.open(EPUB_IMPORT_DIR);
  if (!dir) return;
  while (File entry = dir.openNextFile()) {
    if (!entry.isDirectory()) {
      String name = String(entry.name());
      String lower = name; lower.toLowerCase();
      if (lower.endsWith(".epub")) epubFileList.push_back(name);
    }
    entry.close();
  }
  dir.close();
  sortStrings(epubFileList);
}

void drawEpubPickerMenu() {
  tft.fillScreen(ILI9341_BLACK);
  tft.setTextSize(2);
  tft.setTextColor(ILI9341_YELLOW);
  tft.setCursor(6, 4);
  tft.println("Import EPUB");
  tft.drawFastHLine(0, 26, SCREEN_W, ILI9341_YELLOW);

  if (epubFileList.empty()) {
    tft.setTextColor(ILI9341_WHITE);
    tft.setTextSize(1);
    tft.setCursor(6, 40);
    tft.println("No .epub files found.");
    tft.setCursor(6, 54);
    tft.println("Copy .epub files to:");
    tft.setCursor(6, 66);
    tft.println(EPUB_IMPORT_DIR);
    tft.setCursor(6, 84);
    tft.println("on the SD card, then");
    tft.setCursor(6, 96);
    tft.println("re-open this menu.");
    return;
  }

  if (epubIndex < menuScrollTop) menuScrollTop = epubIndex;
  if (epubIndex >= menuScrollTop + MENU_VISIBLE_ROWS) menuScrollTop = epubIndex - MENU_VISIBLE_ROWS + 1;

  int y = 32;
  for (int i = menuScrollTop; i < (int)epubFileList.size() && i < menuScrollTop + MENU_VISIBLE_ROWS; i++) {
    bool isSel = (i == epubIndex);
    tft.fillRect(0, y, SCREEN_W, 20, isSel ? ILI9341_BLUE : ILI9341_BLACK);
    tft.setTextColor(isSel ? ILI9341_WHITE : ILI9341_LIGHTGREY);
    tft.setCursor(6, y + 2);
    tft.println(epubFileList[i]);
    y += 20;
  }
}

void drawImportProgress(const String &line1, const String &line2) {
  tft.fillScreen(ILI9341_BLACK);
  tft.setTextColor(ILI9341_YELLOW);
  tft.setTextSize(2);
  tft.setCursor(6, 6);
  tft.println("Importing...");
  tft.drawFastHLine(0, 28, SCREEN_W, ILI9341_YELLOW);
  tft.setTextColor(ILI9341_WHITE);
  tft.setTextSize(1);
  tft.setCursor(6, 40);
  tft.println(line1);
  tft.setCursor(6, 54);
  tft.println(line2);
}

// Strips characters that are unsafe/problematic in FAT32 filenames.
String sanitizeFilename(const String &in) {
  String out;
  out.reserve(in.length());
  for (unsigned int i = 0; i < in.length(); i++) {
    char c = in[i];
    if (c == '\\' || c == '/' || c == ':' || c == '*' || c == '?' ||
        c == '"'  || c == '<' || c == '>' || c == '|' || (uint8_t)c < 32) {
      continue; // drop it
    }
    out += c;
  }
  out.trim();
  if (out.length() == 0) out = "Untitled";
  if (out.length() > 48) out = out.substring(0, 48);
  return out;
}

// Reads the whole current zip entry into a String, in small chunks
// (works for files larger than available stack/heap chunk size).
String readCurrentZipEntry(UNZIP &zip, uint32_t expectedSize) {
  String result;
  result.reserve(expectedSize + 16);
  uint8_t buf[512];
  int32_t n;
  zip.openCurrentFile();
  while ((n = zip.readCurrentFile(buf, sizeof(buf))) > 0) {
    for (int32_t i = 0; i < n; i++) result += (char)buf[i];
  }
  zip.closeCurrentFile();
  return result;
}

// Finds the path of the .opf file inside the epub by scanning all entries
// (simpler and in practice just as reliable as parsing META-INF/container.xml
// for the vast majority of real EPUB files, which have exactly one .opf).
String findOpfPath(UNZIP &zip) {
  char szName[256];
  unz_file_info fi;
  zip.gotoFirstFile();
  int rc = UNZ_OK;
  while (rc == UNZ_OK) {
    rc = zip.getFileInfo(&fi, szName, sizeof(szName), NULL, 0, NULL, 0);
    if (rc == UNZ_OK) {
      String name = String(szName);
      String lower = name; lower.toLowerCase();
      if (lower.endsWith(".opf")) return name;
    }
    rc = zip.gotoNextFile();
  }
  return "";
}

String dirnameOf(const String &path) {
  int idx = path.lastIndexOf('/');
  if (idx < 0) return "";
  return path.substring(0, idx + 1);
}
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
